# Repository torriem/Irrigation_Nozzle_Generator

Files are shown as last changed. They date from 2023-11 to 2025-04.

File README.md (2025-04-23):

Occasionally I loose a complete sprinkler from a pivot.  Although I keep spare regulator and sprinkler units on the shelf, I don't always have the correct nozzle size on hand. This OpenSCAD file creates print-able nozzles for iWob, iWob2, and Nelson -style irrigation sprinklers, using OEM standard size numbers.  Adjust the tolerance to get the oriface to the correct size. iWob and iWob2 nozzles are sized in 64ths of an inch, with in-between sizes of 0.5.  For example 18/64ths or 18.5/64ths.  Nelson uses 128ths of an inch.  For example 37/128th.

Disclaimer: these nozzles should only be used temporarily until the correct nozzle is purchased as the size may not be very accurate compared to the injection-molded OEM nozzles.

There are several parameters in the SCAD file that can be changed:

- size - size number of iwob or iwob2 nozzles (in 64ths of an inch)
- nelson_size - size number of nelson nozzle (in 128th of an inch)
- model - one of "iwob" "iwob2" "nelson" or "all".  Specify what kind of nozzle to create.  All creates one of each kind in the same file
- nozzle_tolerance - how many mm oversize to make the hole, to account for printer inprecision.  For the X1 Carbon with ABS, 0.12mm oversize ends up about right.  Can measure certain sizes with drill bit shanks.

I recommend printing the IWob2-style nozzles on the angled flat face that the number is embossed in.  Should print without any supports on most printers. The other nozzles can be printed in the verticle orientation without supports.

Those parameters can be passed on the command-line with `-D`.  For example:

```
openscad -D 'model="iwob"' -D 'size=19.5' -o iwob_19_5.stl irrigation_nozzle.scad
```

A script could generate a complete set of stl files using these parameters.

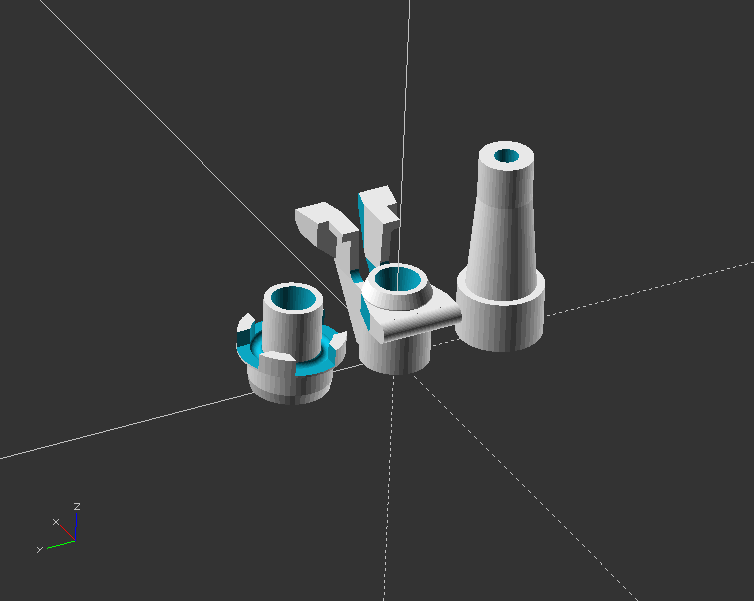
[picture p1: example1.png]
example1

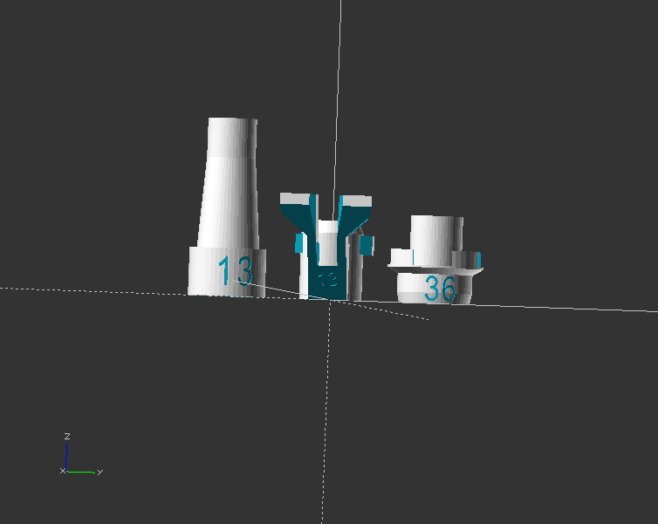
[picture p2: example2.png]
example2


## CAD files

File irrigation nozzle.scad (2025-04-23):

/* Copyright 2024 Michael Torrie */
/* Licensed under the terms of the GPLv3 */

$fn=50;
/* If using command line, use -D 'model="xxx"' where xxx is one of
   iwob, iwob2, or nelson.  Use -D 'size=##' to set the size, using
   standard iwob and nelson size numbers.abs
 */
nozzle_tolerance = 0.12; //mm over-size nozzle hole

font =  "Arial Narrow";
model = "iwob"; //set this to iwob2, iwob, or nelson
size = 10;
nelson_size = 36;

if (model == "iwob2") {
	iwob2_nozzle(size);
} else if (model == "iwob") {
	iwob_nozzle(size);
} else if (model == "nelson") {
	nelson_nozzle(nelson_size);
} else {
	//otherwise comment out what you don't want, and set the size
	//number in the example calls below:

	iwob2_nozzle(size);
	translate([0,-25, 0])
		iwob_nozzle(size);

	translate([0,25,0])
		nelson_nozzle(nelson_size);
}

//Create an iWob nozzle of a given size, which is
//in 64ths of an inch.  Compatible with original
//iWob sprinklers
module iwob_nozzle(nozzle_number) {
	nozzle_radius = (nozzle_number / 64.0 * 25.4 + nozzle_tolerance) / 2;
	difference () {
		//Outside of nozzle
		union() {
			cylinder(11.5,9.25,9.25); //base
			translate([0,0,11.5]) {
				cylinder(21.75,7.5,5.85); //taper
			}
			translate([0,0,33.25]) {
				cylinder(h=9.5,r=5.85); //nozzle part
			}
		}

		//nozzle hole through the center of nozzle
		union() {
			translate([0,0,-1]) {
				cylinder(11.55,7.25,5.25);
			}
			translate([0,0,10.5]) {
				cylinder(27.25,5.25,nozzle_radius);
			}
			translate([0,0,37.74]) {
				cylinder(h=6, r=nozzle_radius);
			}
		}

		//Add nozzle number text
		RADIUS=9.25;
		stext = (nozzle_number < 10 ? str("0",nozzle_number) : str(nozzle_number));
		chars = len( stext );
		ARC_ANGLE=(chars > 2 ? 120 : 65);

		translate([0,0,6]) {
			for(i=[0:1:chars]){
				rotate([0,0,i*ARC_ANGLE/chars]){
					translate( [RADIUS*.94,0,0])
						rotate([90,0,90])
						linear_extrude(1)
							offset(r=0.01) //offset fixes bad font outlines
								text(stext[i],size=7,font=font, valign="center",halign="center");
				}
			}
		}
	}
}

module iwob2_nozzle(nozzle_number) {
	nozzle_radius = (nozzle_number / 64.0 * 25.4 + nozzle_tolerance) / 2;

	difference() {
		union() {
			nozzle_outer();
			translate([0,0,13.4])
				pivot_feature();
			keeper1();
		}
		union() {
			translate([0,0,-1])
				cylinder(6.01,nozzle_radius,nozzle_radius);
			translate([0,0,5])
				cylinder(15.01,nozzle_radius,5);
		}
		nozzle_text();           
	}
	//nozzle_text();           

	module nozzle_text() {

		/*
		   nozzle_string = (nozzle_number - floor(nozzle_number)) > 0.1 
		   ? str(floor (nozzle_number / 10), ".", 
		   floor (nozzle_number - floor (nozzle_number / 10)  * 10)) 
		   : str(nozzle_number);
		 */
		/*
		   nozzle_string = (nozzle_number - floor(nozzle_number)) > 0.1 
		   ? str(floor (nozzle_number))
		   : str(nozzle_number);
		 */
		nozzle_string = str(nozzle_number);
		//echo (nozzle_string);

		translate([11.4,0,5]) {
			rotate([37+90,0,90]) {
				letter(nozzle_string,4,4);
			}
		}
	}


	module latch_fillet() {
		translate([10,0,15.5])
			rotate([90,0,0])
			cylinder(40,2,2, center = true);
	}
	module keeper_cut3() {
		translate([25-7.5,0,0])
			rotate([0,0,90])
			rotate([90,0,0])
			linear_extrude(7.5) {
				polygon( points = [ [-4.66,15], [-4.7-7,14.9], [-4.7-7,15+6] ]);
			}
	}

	module keeper_cut2() {
		l1 = 4.25;
		l2 = 8.8;

		linear_extrude(50) {
			polygon( points = [ [17.5,l1/2], [26.5,l2/2],
					[26.5,-l2/2], [17.5,-l1/2] ]);
		}

	}

	module keeper_cut1() {
		translate([0,20,0])
			rotate([90,0,0])
			linear_extrude(40) {
				polygon( points = [ [ 8,-0.01], [8+19,-0.01],
						[ 8+19,25] ]);
			}
	}

	module keeper3() {
		translate([0,0,15])
			linear_extrude(10) {
				polygon(points = [ [18,-3], [18+7,-3],
						[18+7, -11], [18,-9.5]
				]);
			}
	}

	module keeper2() {
		//locking tabs
		translate([12,0,0])
			rotate([90,0,0])
			rotate([0,90,0])
			linear_extrude(13) {
				//points taken from FreeCAD sketch and extruded
				polygon(points=[ [-2.5,13.5], [-4.625,13.5], 
						[-4.85,23], [-6.85,23],
						[-6.85,25], [-2.85,25]]); 
			}
	}

	module keeper1() {
		//Form the locking tabs
		difference() {
			union() {
				translate([5.904,-4.625,0]) {
					difference() {
						union(){
							cube([17.5,9.25,13.5]);
							translate([4,0,13.5])
								cube([2.2,9.25,2]);
						}
						translate([0,2.125,8])
							cube([18,5,8]);
					}
				}

				keeper2();
				mirror([0,1,0])
					keeper2();

				keeper3();
				mirror([0,1,0])
					keeper3();

			}

			keeper_cut1();
			keeper_cut2();

			keeper_cut3();
			mirror([0,1,0])
				keeper_cut3();

			latch_fillet();

		}
	}
	module nozzle_outer() {
		union() {
			cylinder(16,7.5,7.5);
			translate([0,0,16])
				cylinder(3,7.5,6.25);
		}
	}

	module pivot_feature() {
		pivot_width = 18.5;

		difference() {
			union() {
				//unclipped shape with rounded edge
				translate([-9.15,0,0])
					rotate([90,0,0])
					cylinder(pivot_width,2.35,2.35, center = true);

				translate([-2.075,0,0])
					cube([14.15,pivot_width,4.7], center = true);
			}


			translate([-6,0,-2.355]) { 
				//shape to trim with, rough tangent to circle
				difference() {
					union() {
						translate([9,-7.5,0]) {
							cube([10,15,4.8]);
						}

						translate([0,9.5,0]) {
							rotate([0,0,-15.85])
								cube([20,5,4.8]);
						}
						translate([0,-9.5,0]) {
							rotate([0,0,15.85]) {
								translate([0,-5,0])
									cube([20,5,4.8]);
							}
						}
					}
					translate([6,0,-1]) {
						cylinder(6,7.5,7.5);
					}
				}
			}
		}
	}
}

//generate a nelson-style nozzle of a given size,
//which is in 128ths of an inch
module nelson_nozzle(nelson_nozzle_number) {

	nozzle_radius = (nelson_nozzle_number / 128.0 * 25.4 + nozzle_tolerance) / 2;
	//echo (nelson_nozzle_number);
	//echo ("nozzle radius is ", nozzle_radius);
	difference() {
		//Outer shape

		union() {
			difference() {
				union() {
					cylinder(2.5,8.5,9);
					translate([0,0,2.5]) {
						cylinder(4.5,9,9);
					}
					/* large flat part where o-ring will sit */
					translate([0,0,7]) {
						cylinder(1.5,9,11.5);
					}
					translate([0,0,8.5]) {
						cylinder(4.25,11.5,11.5);
					}

				}

				/* cut out notches to mate with upper body threaded part */
				translate([0,0,9]) {
					translate([0,0,2.5]){
						union() {
							cube([56,9.5,5],center=true);
							rotate([0,0,90]) {
								cube([56,9.5,5],center=true);
							}
						}        
					}
				}
				/* o-ring channel */
				translate([0,0,9]) {
					rotate_extrude(angle=360) {
						translate([7.5,0]) {
							circle(d=2.5);
						}
					}
				}
				/* part that's inserted into upper body */
				translate([0,0,9]) {
					difference() {
						cylinder(4.25,8.75,8.75);
						cylinder(10,6.25,6.25, center=true);
					}        
				}
			}
			cylinder(21,6.25,6.25);
		}

		//inner nozzle
		union() {
			translate([0,0,-1]) {
				cylinder(7.1,nozzle_radius,nozzle_radius);
			}
			translate([0,0,6]) {
				cylinder(15.5,nozzle_radius,4.75);
			}
		}

		//Add nozzle number text
		RADIUS=9;
		stext = (nelson_size < 10 ? str("0",nelson_size) : str(nelson_size));
		chars = len( stext );
		ARC_ANGLE=55;

		translate([0,0,3.5]) {
			for(i=[0:1:chars]){
				rotate([0,0,i*ARC_ANGLE/chars]){
					translate( [RADIUS*.93,0,0])
						rotate([90,0,90])
						linear_extrude(1.5)
							offset(r=0.01) //offset fixes bad font outlines
								text(stext[i],size=6,font=font, valign="center",halign="center");
				}
			}
		}
		
	}
}

module letter(l, letter_size = 5, letter_height = 0.4) {
	// Use linear_extrude() to make the letters 3D objects as they
	// are only 2D shapes when only using text()
	linear_extrude(height = letter_height) {
		offset(r=0.01) //offset fixes bad font outlines
			text(l, size = letter_size, font = font, halign = "center", valign = "center", $fn = 16);
	}
}

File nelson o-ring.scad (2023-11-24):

$fn=50;
					
difference() {
	rotate_extrude(angle=360) {
		translate([7.5,0]) {
			circle(d=2.2);
		}
	}

	translate([0,0,-1.40]) {
		rotate_extrude(angle=360) {
			translate([7.5,0]) {
				square(size=[2.2,2], center=true);
			}
		}
	}
}

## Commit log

2023-11-24 fixed problem where number 6 in arial narrow did not result in a closed mesh. Solution is to use a very small offset around the text shape.
    [irrigation nozzle.scad, nelson o-ring.scad]
2023-11-24 Fixed nelson nozzle size bug
    [irrigation nozzle.scad]
2025-04-23 Added license file.
    [irrigation nozzle.scad]
2025-04-23 Printing orientation
